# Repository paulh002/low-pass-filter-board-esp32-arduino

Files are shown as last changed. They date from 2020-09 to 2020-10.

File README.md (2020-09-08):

# low-pass-filter-board-esp32-arduino
Lowpass filter board managed by ESP32

Low pass filter for RF amp managed by ESP32 VFO or RF Amp / SWR meter (also ESP32).
I use the same PCB as the VFO as controler but do not install the VFO components like si5351. The LPF can be direct managed from VFO software or stand alone with SWR / RFAMP software, from Loftur Jonasson, TF3LJ / VE2LJX (PSWR_T software). I made an adaption of this software for ESP32 and Adafruit 2.8 display. But I am not completly happy with it. Because it uses fixed spaced fonts which are not available in adafruit library. But for now it works with some GUI bugs which I still need to fix.
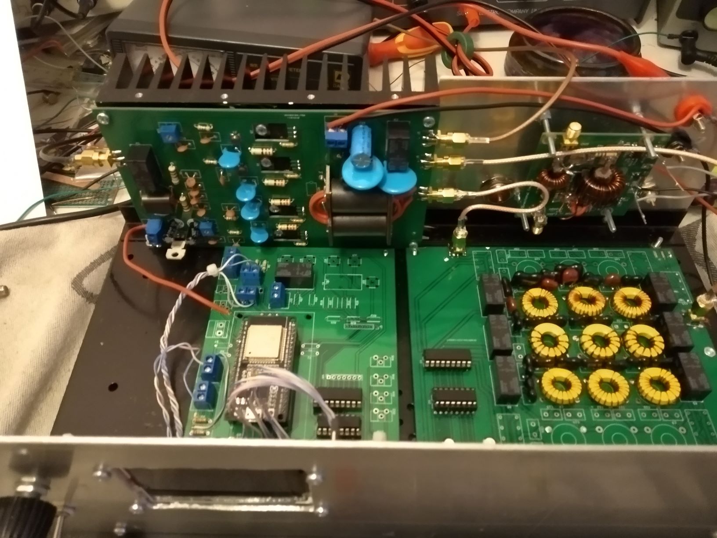
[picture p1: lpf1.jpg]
VFO


Here the LPF build in into my tranceiver and managed by esp32 VFO.
VFO

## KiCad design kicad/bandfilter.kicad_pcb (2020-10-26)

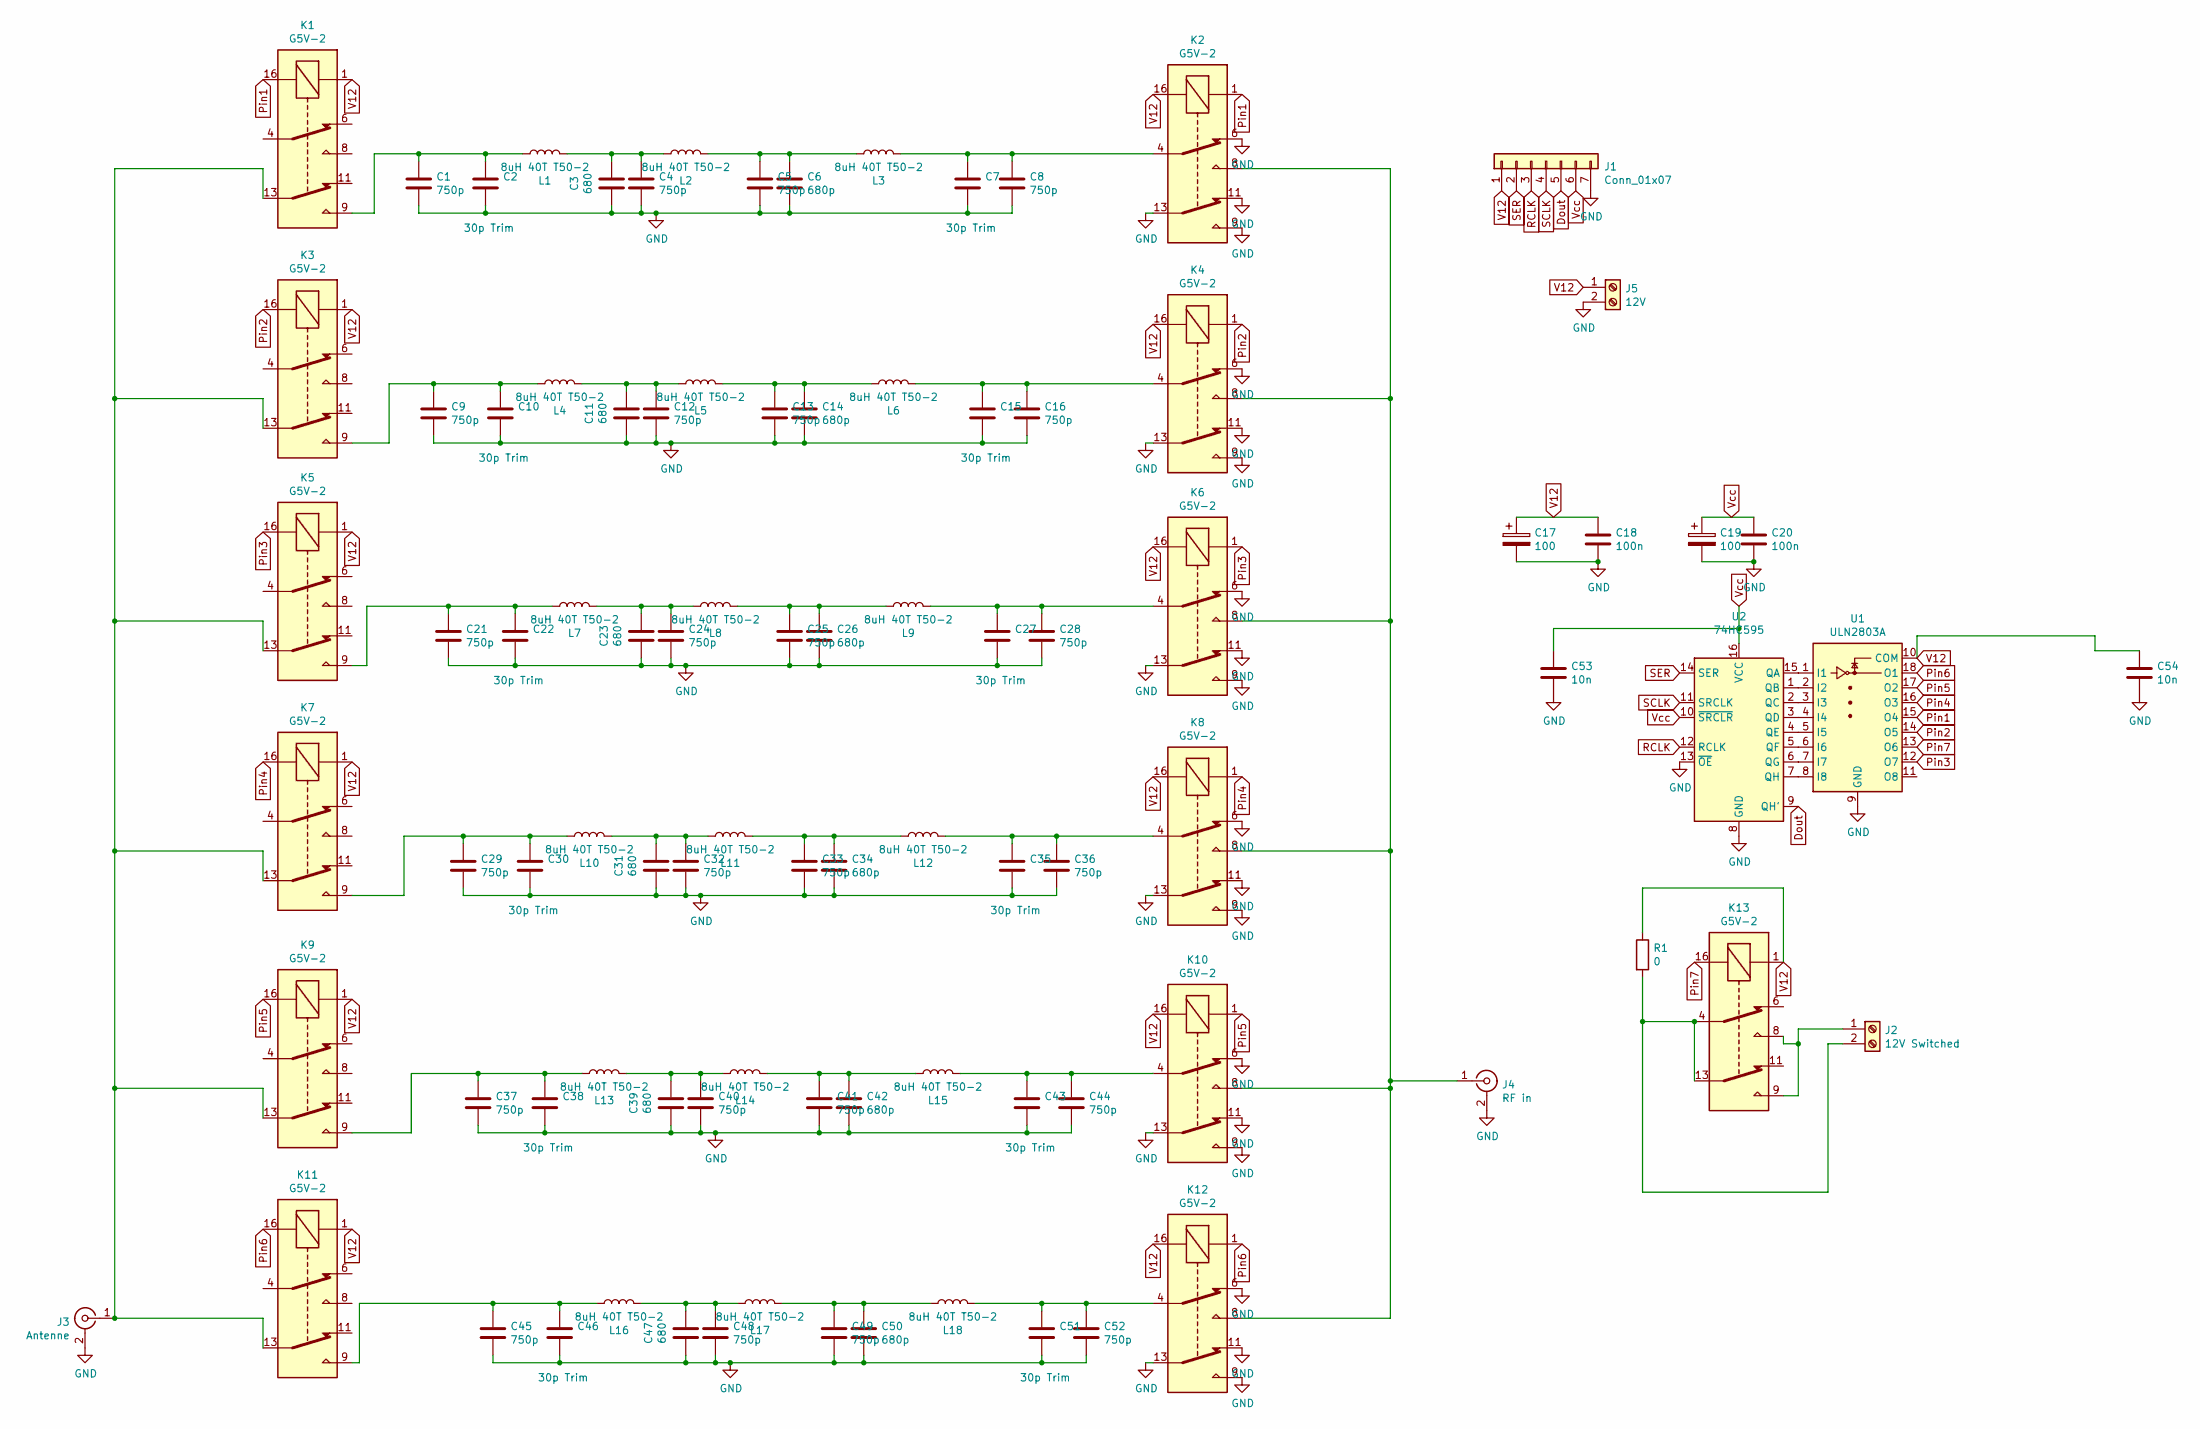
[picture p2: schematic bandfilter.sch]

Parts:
C1, C4, C5, C8, C9, C12, C13, C16, C21, C24, C25, C28, C29, C32, C33, C36, C37, C40, C41, C44, C45, C48, C49, C52: 750p; C_Disc_D9.0mm_W5.0mm_P5.00mm
C2, C7, C10, C15, C22, C27, C30, C35, C38, C43, C46, C51: 30p Trim; C_Disc_D9.0mm_W5.0mm_P5.00mm
C3, C11, C23, C31, C39, C47: 680; C_Disc_D9.0mm_W5.0mm_P5.00mm
C6, C14, C26, C34, C42, C50: 680p; C_Disc_D9.0mm_W5.0mm_P5.00mm
C17, C19: 100; CP_Radial_D8.0mm_P5.00mm
C18, C20: 100n; C_Disc_D9.0mm_W5.0mm_P5.00mm
C53, C54: 10n; C_Disc_D9.0mm_W5.0mm_P5.00mm
J1: Conn_01x07; PinSocket_1x07_P2.54mm_Vertical
J2: 12V Switched; TerminalBlock_MetzConnect_Type011_RT05502HBWC_1x02_P5.00mm_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
J3: Antenne; SMA_Amphenol_132134_Vertical
J4: RF in; SMA_Amphenol_132134_Vertical
J5: 12V; TerminalBlock_MetzConnect_Type011_RT05502HBWC_1x02_P5.00mm_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
K1, K2, K3, K4, K5, K6, K7, K8, K9, K10, K11, K12, K13: G5V-2; Relay_DPDT_Omron_G5V-2
L1, L2, L3, L4, L5, L6, L7, L8, L9, L10, L11, L12, L13, L14, L15, L16, L17, L18: 8uH 40T T50-2; Transformer_Toroid_Horizontal_D14.0mm_Amidon-T50
R1: 0; R_Axial_DIN0204_L3.6mm_D1.6mm_P2.54mm_Vertical
U1: ULN2803A; DIP-18_W7.62mm
U2: 74HC595; DIP-16_W7.62mm_LongPads

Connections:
Dout: J1.5, U2.9 (QH')
GND: C1.1, C2.1, C3.2, C4.1, C5.1, C6.1, C7.1, C8.1, C9.1, C10.1, C11.2, C12.1, C13.1, C14.1, C15.1, C16.1, C17.2, C18.1, C19.2, C20.1, C21.1, C22.1, C23.2, C24.1, C25.1, C26.1, C27.1, C28.1, C29.1, C30.1, C31.2, C32.1, C33.1, C34.1, C35.1, C36.1, C37.1, C38.1, C39.2, C40.1, C41.1, C42.1, C43.1, C44.1, C45.1, C46.1, C47.2, C48.1, C49.1, C50.1, C51.1, C52.1, C53.1, C54.1, J1.7, J3.2 (Ext), J4.2 (Ext), J5.2, K2.6, K2.9, K2.11, K2.13, K4.6, K4.9, K4.11, K4.13, K6.6, K6.9, K6.11, K6.13, K8.6, K8.9, K8.11, K8.13, K10.6, K10.9, K10.11, K10.13, K12.6, K12.9, K12.11, K12.13, U1.9 (GND), U2.8 (GND), U2.13 (~OE)
unnamed: C1.2, C2.2, K1.9, L1.1
unnamed: C3.1, C4.2, L1.2, L2.1
unnamed: C5.2, C6.2, L2.2, L3.1
unnamed: C7.2, C8.2, K2.4, L3.2
unnamed: C9.2, C10.2, K3.9, L4.1
unnamed: C11.1, C12.2, L4.2, L5.1
unnamed: C13.2, C14.2, L5.2, L6.1
unnamed: C15.2, C16.2, K4.4, L6.2
unnamed: C21.2, C22.2, K5.9, L7.1
unnamed: C23.1, C24.2, L7.2, L8.1
unnamed: C25.2, C26.2, L8.2, L9.1
unnamed: C27.2, C28.2, K6.4, L9.2
unnamed: C29.2, C30.2, K7.9, L10.1
unnamed: C31.1, C32.2, L10.2, L11.1
unnamed: C33.2, C34.2, L11.2, L12.1
unnamed: C35.2, C36.2, K8.4, L12.2
unnamed: C37.2, C38.2, K9.9, L13.1
unnamed: C39.1, C40.2, L13.2, L14.1
unnamed: C41.2, C42.2, L14.2, L15.1
unnamed: C43.2, C44.2, K10.4, L15.2
unnamed: C45.2, C46.2, K11.9, L16.1
unnamed: C47.1, C48.2, L16.2, L17.1
unnamed: C49.2, C50.2, L17.2, L18.1
unnamed: C51.2, C52.2, K12.4, L18.2
unnamed: J2.1, K13.8, K13.9
unnamed: J2.2, K13.4, K13.13, R1.2
unnamed: J3.1 (In), K1.13, K3.13, K5.13, K7.13, K9.13, K11.13
unnamed: J4.1 (In), K2.8, K4.8, K6.8, K8.8, K10.8, K12.8
unnamed: U1.1 (I1), U2.15 (QA)
unnamed: U1.2 (I2), U2.1 (QB)
unnamed: U1.3 (I3), U2.2 (QC)
unnamed: U1.4 (I4), U2.3 (QD)
unnamed: U1.5 (I5), U2.4 (QE)
unnamed: U1.6 (I6), U2.5 (QF)
unnamed: U1.7 (I7), U2.6 (QG)
unnamed: U1.8 (I8), U2.7 (QH)
Pin1: K1.16, K2.1, U1.15 (O4)
Pin2: K3.16, K4.1, U1.14 (O5)
Pin3: K5.16, K6.1, U1.12 (O7)
Pin4: K7.16, K8.1, U1.16 (O3)
Pin5: K9.16, K10.1, U1.17 (O2)
Pin6: K11.16, K12.1, U1.18 (O1)
Pin7: K13.16, U1.13 (O6)
RCLK: J1.3, U2.12 (RCLK)
SCLK: J1.4, U2.11 (SRCLK)
SER: J1.2, U2.14 (SER)
V12: C17.1, C18.2, C54.2, J1.1, J5.1, K1.1, K2.16, K3.1, K4.16, K5.1, K6.16, K7.1, K8.16, K9.1, K10.16, K11.1, K12.16, K13.1, R1.1, U1.10 (COM)
Vcc: C19.1, C20.2, C53.2, J1.6, U2.10 (~SRCLR), U2.16 (VCC)

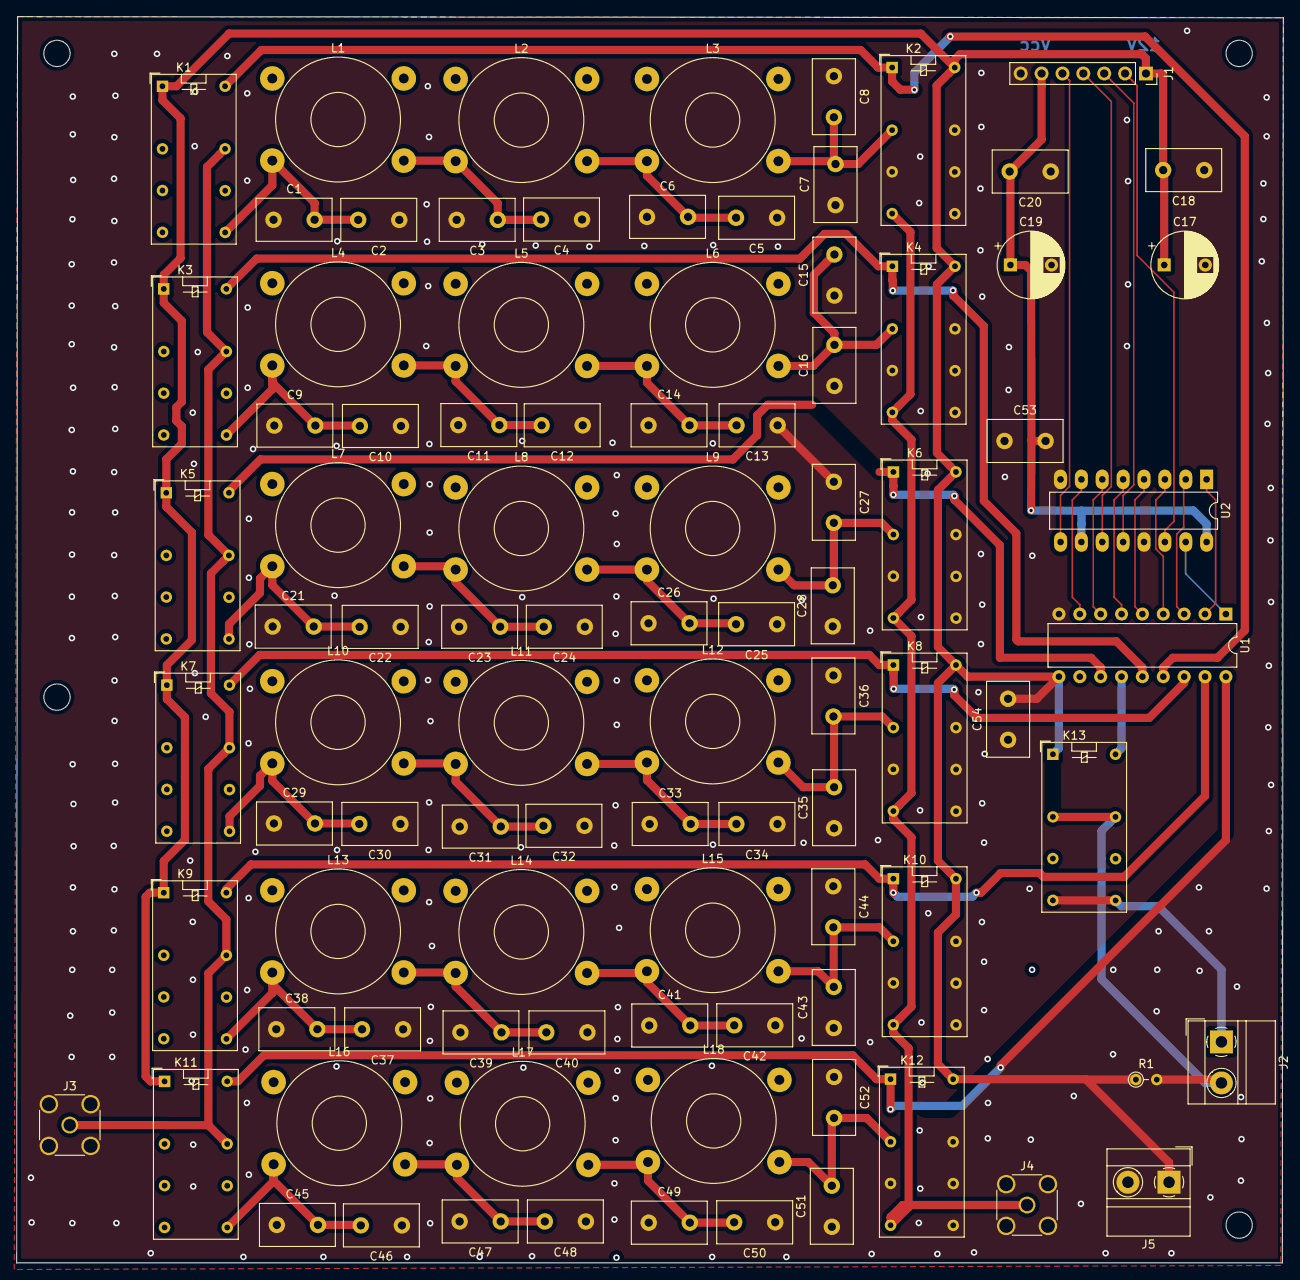
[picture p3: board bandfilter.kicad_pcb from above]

Board: 2 copper layers, 154.2 x 151.7 mm, 97 parts (0 on the bottom side), 50 nets.

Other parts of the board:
 : MountingHole_3.2mm_M3
 #2,  #3,  #4: MountingHole_3.2mm_M3
